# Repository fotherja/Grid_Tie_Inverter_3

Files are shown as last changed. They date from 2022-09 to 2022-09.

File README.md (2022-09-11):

# Grid_Tie_Inverter_3
Software and Hardware for GTI v3

Here the software and hardware files for the Grid Tie inverter project I'm working on. This is version 3. More to come soon.

I use STMCubeIDE for the software developer. I have used the CMSIS DSP library to do FFTs

I used Kicad to design the PCBs and the files are included here too

I'm working on a writeup - not quite finished yet.

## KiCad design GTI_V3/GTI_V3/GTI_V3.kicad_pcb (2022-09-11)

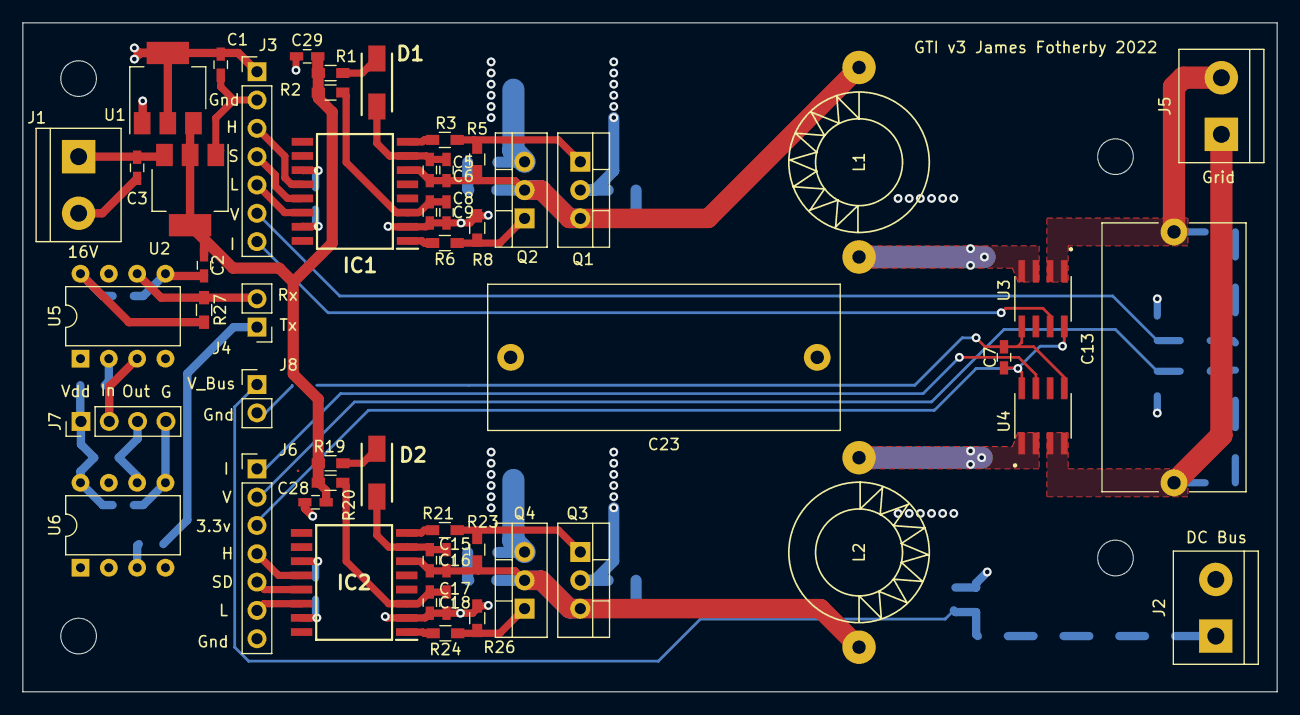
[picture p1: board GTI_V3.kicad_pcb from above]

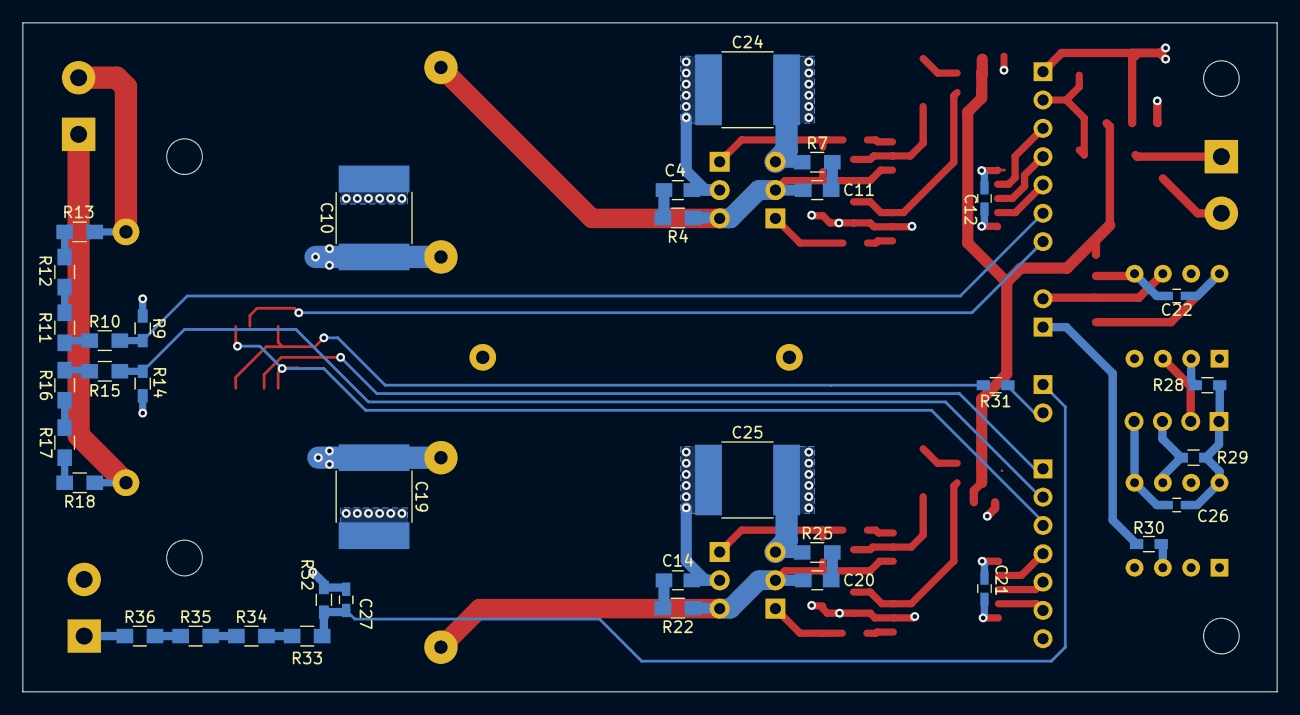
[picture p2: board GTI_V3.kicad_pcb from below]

Board: 4 copper layers, 112.5 x 60.0 mm, 89 parts (36 on the bottom side), 58 nets.

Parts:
C1, C2, C3: 10uF; C_0603_HandSoldering
C4, C11, C14, C20: 22pF; C_0805_HandSoldering
C5, C7, C8, C12, C15, C17, C21, C22, C26, C28, C29: 100nF; C_0603_HandSoldering
C6, C9, C16, C18: 2.2uF; C_0603_HandSoldering
C10, C19: C; C_2225_HandSoldering
C13: 2uF; C_Rect_L24.0mm_W12.8mm_P22.50mm_MKT
C23: 10uF; C_Rect_L31.5mm_W13.0mm_P27.50mm_MKS4
C24, C25: 0.47uF; C_2225_HandSoldering
C27: 10nF; C_0603_HandSoldering
D1, D2: ES1J; DIOM5227X250N
IC1, IC2: DGD2110S16-13; SOIC127P1032X264-16N
J1, J2, J5: Screw_Terminal_01x02; TerminalBlock_bornier-2_P5.08mm
J3, J6: Conn_01x07_Male; Socket_Strip_Straight_1x07_Pitch2.54mm
J4, J8: Conn_01x02_Male; Socket_Strip_Straight_1x02_Pitch2.54mm
J7: Conn_01x04_Male; Socket_Strip_Straight_1x04_Pitch2.54mm
L1, L2: L; Choke_Toroid_horizontal_Diameter12-5mm_Amidon-T44
Q1, Q2, Q3, Q4: STF35N60DM2; TO-220-3_Vertical
R1, R2, R19, R20: 2.2R; R_0603_HandSoldering
R3, R6, R21, R24: 4.7R; R_0603_HandSoldering
R4, R7, R22, R25: 15R; R_0805_HandSoldering
R5, R8, R23, R26: 10K; R_0603_HandSoldering
R9, R14, R32: 2.2K; R_0603_HandSoldering
R10, R11, R12, R13, R15, R16, R17, R18, R33, R34, R35, R36: 100K; R_0805_HandSoldering
R27, R29: 470R; R_0603_HandSoldering
R28, R30: 330R; R_0603_HandSoldering
R31: 0R; R_0603_HandSoldering
U1: NCP1117-3.3_SOT223; SOT-223-3_TabPin2
U2: NCP1117-12_SOT223; SOT-223-3_TabPin2
U3, U4: ACS722LLCTR-05AB-T; SOIC127P600X175-8N
U5, U6: 6N137; DIP-8_W7.62mm

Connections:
+3V3: C1.1, C7.1, C12.1, C21.1, C22.1, IC1.11 (VDD), IC2.11 (VDD), J3.1, J6.3, R27.2, U1.2 (VO), U3.8 (VCC), U4.8 (VCC), U5.8 (VCC), U6.2 (A)
+12V: C2.1, C28.1, C29.1, R1.2, R2.2, R19.2, R20.2, U1.3 (VI), U2.2 (VO)
/Ext_Gnd: C26.2, J7.4, U6.5 (GND)
/Ext_Rx: J7.3, R29.1, U6.6 (VO)
/Ext_Tx: J7.2, U5.3 (C)
/Ext_Vdd: C26.1, J7.1, R28.2, R29.2, U6.8 (VCC)
/I_Sense_A: J3.7, U3.7 (VIOUT)
/I_Sense_B: J6.1, U4.7 (VIOUT)
/Rx: J4.2, R27.1, U5.6 (VO)
/Tx: J4.1, R30.1
/VBUS_Sense: C27.1, J8.1, R32.2, R33.2
/V_Sense_A: J3.6, R9.2, R10.2
/V_Sense_B: J6.2, R14.2, R15.2
GND: C1.2, C2.2, C3.2, C8.2, C9.2, C10.2, C12.2, C17.2, C18.2, C19.2, C21.2, C22.2, C23.2, C24.2, C25.2, C27.2, C28.2, C29.2, IC1.2 (COM), IC1.15 (VSS), IC2.2 (COM), IC2.15 (VSS), J1.2, J2.2, J3.2, J6.7, J8.2, Q2.3 (S), Q4.3 (S), R7.1, R8.2, R9.1, R14.1, R25.1, R26.2, R31.1, R32.1, U1.1 (GND), U2.1 (GND), U5.5 (GND)
GNDA: C7.2, R31.2, U3.5 (GND), U4.5 (GND)
unnamed: C4.2, R4.2
unnamed: C5.1, C6.1, D1.1, IC1.7 (VB)
unnamed: C8.1, C9.1, IC1.3 (VCC), R2.1
unnamed: C10.1, L1.2, U3.3 (IP-), U3.4 (IP-)
unnamed: C5.2, C6.2, C11.1, IC1.6 (VS), L1.1, Q1.3 (S), Q2.2 (D), R4.1, R5.2
unnamed: C11.2, R7.2
unnamed: C13.1, J5.2, R13.1, U3.1 (IP+), U3.2 (IP+)
unnamed: C13.2, J5.1, R18.1, U4.3 (IP-), U4.4 (IP-)
unnamed: C14.2, R22.2
unnamed: C15.1, C16.1, D2.1, IC2.7 (VB)
unnamed: C15.2, C16.2, C20.1, IC2.6 (VS), L2.1, Q3.3 (S), Q4.2 (D), R22.1, R23.2
unnamed: C17.1, C18.1, IC2.3 (VCC), R20.1
unnamed: C19.1, L2.2, U4.1 (IP+), U4.2 (IP+)
unnamed: C20.2, R25.2
unnamed: D1.2, R1.1
unnamed: D2.2, R19.1
unnamed: IC1.1 (LO), R6.2
unnamed: IC1.8 (HO), R3.2
unnamed: IC1.12 (HIN), J3.3
unnamed: IC1.13 (SD), J3.4
unnamed: IC1.14 (LIN), J3.5
unnamed: IC2.1 (LO), R24.2
unnamed: IC2.8 (HO), R21.2
unnamed: IC2.12 (HIN), J6.4
unnamed: IC2.13 (SD), J6.5
unnamed: IC2.14 (LIN), J6.6
unnamed: Q1.1 (G), R3.1, R5.1
unnamed: Q2.1 (G), R6.1, R8.1
unnamed: Q3.1 (G), R21.1, R23.1
unnamed: Q4.1 (G), R24.1, R26.1
unnamed: R10.1, R11.2
unnamed: R11.1, R12.2
unnamed: R12.1, R13.2
unnamed: R15.1, R16.2
unnamed: R16.1, R17.2
unnamed: R17.1, R18.2
unnamed: R28.1, U5.2 (A)
unnamed: R30.2, U6.3 (C)
unnamed: R33.1, R34.2
unnamed: R34.1, R35.2
unnamed: R35.1, R36.2
VBUS: C4.1, C14.1, C23.1, C24.1, C25.1, J2.1, Q1.2 (D), Q3.2 (D), R36.1
VCC: C3.1, J1.1, U2.3 (VI)

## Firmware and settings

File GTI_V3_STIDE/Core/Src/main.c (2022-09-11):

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
/* Includes ------------------------------------------------------------------*/
#include "main.h"
#include "adc.h"
#include "dac.h"
#include "dma.h"
#include "tim.h"
#include "usart.h"
#include "gpio.h"

/* USER CODE BEGIN Includes */
//#define ARM_MATH_CM4 - WE HAVE DONE THIS UNDER OPTIONS FOR TARGET
#include "arm_math.h"
#include "math.h"
#include "support.h"
#include "PID.h"
#include "filter1.h"
#include "filter150.h"
#include "string.h"
#include "stdio.h"
/* USER CODE END Includes */

/* USER CODE BEGIN PD */
#define 		PLL_Kp 					4.0e-3f 								// PID parameters for our PLL tracking control
#define 		PLL_Ki 					2.0e-2f									// PoM: 4.0e-3f, 2.0e-2f
#define 		PLL_Kd 					0.0f
#define 		PLL_LIMIT 				500.0f
#define 		PLL_PERIOD 				7.8e-5f 								// 1 / (50 * 256) seconds
#define 		SINE_STEP_PERIOD 		13125 									// Ticks between incrementing our LO (Local Osc) index for 50Hz sine

//##############################################
#define			FC_Kp 					1.0e-3f									// Fundamental component PI parameter
#define 		FC_Ki 					8.0e-3f									//
#define 		FC_Limits 				1.5f

#define			HC_Kp 					1.0e-3f									// Harmonic component PI parameters
#define 		HC_Ki 					2.0e-3f
#define 		HC_Limits 				1.5f
//##############################################
#define 		SINE_STEPS           	256                         			// Number of steps to build our sine wave in
#define 		DUTY_LIMIT 				1000 									// Our duty width can vary from 0-1024 however we don't want 100% modulation to avoid MOSFET drive bootstrap voltage drop

#define 		I_OFFSET 				-4155 									// These are calibration constants for our hardware
#define 		V_OFFSET 				725
#define 		V_DIVIDER_K 			1.475e-1f
#define 		I_DIVIDER_K 			1.563e-3f
#define 		F_CONVERSION_K 			3.817e-3f

#define 		RMS_LOWER_LIMIT 		100.0f 									// These values are for the grid checks. We disconnect if our metrics are out of these ranges (SI Units)
#define 		RMS_UPPER_LIMIT 		130.0f
#define 		FREQ_DEVIATION_LIMIT 	1.0f
#define			V_BUS_MINIMUM			200.0f
#define 		V_BUS_MAXIMUM 			320.0f
#define 		I_OUTPUT_MAXIMUM 		4.0f

#define 		ENABLE_JOINING_GRID 	true
#define 		GRID_ACCEPTABLE 		1000
#define 		GRID_UNACCEPTABLE 		-1000
#define 		GRID_BAD_FAIL_RATE 		10 										// Some grid checks are allowed to fail for a certain amount of time (eg. Frequency) this parameter determines for how long
#define 		GRID_OK					0


#define 		CONSTRAIN(x,lower,upper) ((x)<(lower)?(lower):((x)>(upper)?(upper):(x)))
/* USER CODE END PD */


/* USER CODE BEGIN PV */
float Sin_LookupF[256] =
{
	0.00,6.28,12.56,18.83,25.09,31.34,37.56,43.77,49.94,56.09,62.20,68.28,74.31,80.30,86.24,92.13,
	97.97,103.74,109.45,115.10,120.68,126.18,131.61,136.96,142.23,147.41,152.50,157.50,162.40,167.21,171.92,176.52,
	181.02,185.41,189.68,193.85,197.89,201.82,205.62,209.30,212.86,216.28,219.58,222.74,225.77,228.67,231.42,234.04,
	236.51,238.85,241.04,243.08,244.98,246.73,248.33,249.78,251.08,252.23,253.23,254.07,254.77,255.31,255.69,255.92,

	256.00,255.92,255.69,255.31,254.77,254.07,253.23,252.23,251.08,249.78,248.33,246.73,244.98,243.08,241.04,238.85,
	236.51,234.04,231.42,228.67,225.77,222.74,219.58,216.28,212.86,209.30,205.62,201.82,197.89,193.85,189.68,185.41,
	181.02,176.52,171.92,167.21,162.40,157.50,152.50,147.41,142.23,136.96,131.61,126.18,120.68,115.10,109.45,103.74,
	97.97,92.13,86.24,80.30,74.31,68.28,62.20,56.09,49.94,43.77,37.56,31.34,25.09,18.83,12.56,6.28,

	0.00,-6.28,-12.56,-18.83,-25.09,-31.34,-37.56,-43.77,-49.94,-56.09,-62.20,-68.28,-74.31,-80.30,-86.24,-92.13,
	-97.97,-103.74,-109.45,-115.10,-120.68,-126.18,-131.61,-136.96,-142.23,-147.41,-152.50,-157.50,-162.40,-167.21,-171.92,-176.52,
	-181.02,-185.41,-189.68,-193.85,-197.89,-201.82,-205.62,-209.30,-212.86,-216.28,-219.58,-222.74,-225.77,-228.67,-231.42,-234.04,
	-236.51,-238.85,-241.04,-243.08,-244.98,-246.73,-248.33,-249.78,-251.08,-252.23,-253.23,-254.07,-254.77,-255.31,-255.69,-255.92,

	-256.00,-255.92,-255.69,-255.31,-254.77,-254.07,-253.23,-252.23,-251.08,-249.78,-248.33,-246.73,-244.98,-243.08,-241.04,-238.85,
	-236.51,-234.04,-231.42,-228.67,-225.77,-222.74,-219.58,-216.28,-212.86,-209.30,-205.62,-201.82,-197.89,-193.85,-189.68,-185.41,
	-181.02,-176.52,-171.92,-167.21,-162.40,-157.50,-152.50,-147.41,-142.23,-136.96,-131.61,-126.18,-120.68,-115.10,-109.45,-103.74,
	-97.97,-92.13,-86.24,-80.30,-74.31,-68.28,-62.20,-56.09,-49.94,-43.77,-37.56,-31.34,-25.09,-18.83,-12.56,-6.28
};

float Cos_LookupF[256] =
{
	256.00,255.92,255.69,255.31,254.77,254.07,253.23,252.23,251.08,249.78,248.33,246.73,244.98,243.08,241.04,238.85,
	236.51,234.04,231.42,228.67,225.77,222.74,219.58,216.28,212.86,209.30,205.62,201.82,197.89,193.85,189.68,185.41,
	181.02,176.52,171.92,167.21,162.40,157.50,152.50,147.41,142.23,136.96,131.61,126.18,120.68,115.10,109.45,103.74,
	97.97,92.13,86.24,80.30,74.31,68.28,62.20,56.09,49.94,43.77,37.56,31.34,25.09,18.83,12.56,6.28,

	0.00,-6.28,-12.56,-18.83,-25.09,-31.34,-37.56,-43.77,-49.94,-56.09,-62.20,-68.28,-74.31,-80.30,-86.24,-92.13,
	-97.97,-103.74,-109.45,-115.10,-120.68,-126.18,-131.61,-136.96,-142.23,-147.41,-152.50,-157.50,-162.40,-167.21,-171.92,-176.52,
	-181.02,-185.41,-189.68,-193.85,-197.89,-201.82,-205.62,-209.30,-212.86,-216.28,-219.58,-222.74,-225.77,-228.67,-231.42,-234.04,
	-236.51,-238.85,-241.04,-243.08,-244.98,-246.73,-248.33,-249.78,-251.08,-252.23,-253.23,-254.07,-254.77,-255.31,-255.69,-255.92,

	-256.00,-255.92,-255.69,-255.31,-254.77,-254.07,-253.23,-252.23,-251.08,-249.78,-248.33,-246.73,-244.98,-243.08,-241.04,-238.85,
	-236.51,-234.04,-231.42,-228.67,-225.77,-222.74,-219.58,-216.28,-212.86,-209.30,-205.62,-201.82,-197.89,-193.85,-189.68,-185.41,
	-181.02,-176.52,-171.92,-167.21,-162.40,-157.50,-152.50,-147.41,-142.23,-136.96,-131.61,-126.18,-120.68,-115.10,-109.45,-103.74,
	-97.97,-92.13,-86.24,-80.30,-74.31,-68.28,-62.20,-56.09,-49.94,-43.77,-37.56,-31.34,-25.09,-18.83,-12.56,-6.28,

	0.00,6.28,12.56,18.83,25.09,31.34,37.56,43.77,49.94,56.09,62.20,68.28,74.31,80.30,86.24,92.13,
	97.97,103.74,109.45,115.10,120.68,126.18,131.61,136.96,142.23,147.41,152.50,157.50,162.40,167.21,171.92,176.52,
	181.02,185.41,189.68,193.85,197.89,201.82,205.62,209.30,212.86,216.28,219.58,222.74,225.77,228.67,231.42,234.04,
	236.51,238.85,241.04,243.08,244.98,246.73,248.33,249.78,251.08,252.23,253.23,254.07,254.77,255.31,255.69,255.92
};

// structures
PIDControl 			PLL_PID; 													// These structures are used to store the respective PID variables
PIDControl 			Sin_50_PID, Cos_50_PID;
PIDControl 			Sin_150_PID, Cos_150_PID;
PIDControl 			Sin_250_PID, Cos_250_PID;
PIDControl 			Sin_350_PID, Cos_350_PID;

struct 				IIR_Filter_Struct V_Phase_Filter, I_Phase_Filter, V_Bus_Filter;

// DMA buffers and flags
volatile uint16_t 	V_Bus_Raw[1]; 												// ADC3 writes here via the DMA
volatile int32_t 	IV_Output_Raw[2]; 											// The DMA writes our synchronously sampled ADC1 & ADC2 samples here (I_Phase A&B and V_Phase A&B alternately)
volatile uint8_t 	HB_Enabled_Flag, UART_Ready_Flag;

// Voltage and Current values
volatile int16_t 	V_Phase_A, V_Phase_B, I_Phase_A, I_Phase_B;
volatile int16_t 	V_Phase_Unfiltered, I_Phase_Unfiltered, V_Bus_Unfiltered;
volatile float 		V_Phase, I_Phase, V_Bus, Mains_RMS_SI, Freq_Offset_SI; 		// These are our filtered SI unit values

volatile uint8_t 	_50_Index = 0;
volatile uint8_t 	_150_Index = 0;
volatile uint8_t 	_250_Index = 0;
volatile uint8_t 	_350_Index = 0;

volatile int16_t 	Grid_Good_Bad_Cnt = GRID_UNACCEPTABLE;
volatile uint8_t 	REQUEST_JOIN = false, Error_Code;
volatile float 		Joining_Amplitude;

char 				UART_Tx_Buffer[48];

volatile float32_t 	Period_Samples[64];
volatile uint8_t 	Period_Index, Calc_FFT_Flag, Phase_Shift;
volatile uint32_t 	Calc_FFT_Counter;

float32_t 			FFT_Input[64];
float32_t 			FFT_Complex_Output[64];



/* USER CODE END PV */

void SystemClock_Config(void);
/* USER CODE BEGIN PFP */
void HAL_ADC_ConvCpltCallback(ADC_HandleTypeDef* hadc);
void HAL_TIM_PeriodElapsedCallback(TIM_HandleTypeDef *htim);
void HAL_UART_TxCpltCallback(UART_HandleTypeDef *huart);
void Initialisations(void);
void HB_Disable(void);
void HB_Enable(void);
/* USER CODE END PFP */

/**
  * @brief  The application entry point.
  * @retval int
  */
int main(void)
{
  /* MCU Configuration--------------------------------------------------------*/

  /* Reset of all peripherals, Initialises the Flash interface and the Systick. */
  HAL_Init();

  /* Configure the system clock */
  SystemClock_Config();

  /* Initialize all configured peripherals */
  MX_GPIO_Init();
  MX_DMA_Init();
  MX_TIM1_Init();
  MX_TIM9_Init();
  MX_TIM10_Init();
  MX_TIM11_Init();
  MX_ADC1_Init();
  MX_ADC2_Init();
  MX_TIM3_Init();
  MX_ADC3_Init();
  MX_TIM2_Init();
  MX_USART2_UART_Init();
  MX_DAC_Init();
  MX_TIM12_Init();
  /* USER CODE BEGIN 2 */

  Initialisations();
  arm_rfft_fast_instance_f32 S;

  uint16_t i;

  /* USER CODE END 2 */

  /* Infinite loop */
  /* USER CODE BEGIN WHILE */
  while (1)
  {
	if(Calc_FFT_Flag == 1)
	{
		Calc_FFT_Flag = 0;

		// 1) Calculate the FFT of our output current waveform
		for(i = 0; i < 64; i++) {
			FFT_Input[i] = Period_Samples[i];
		}

		arm_rfft_fast_init_f32(&S, 64);
		arm_rfft_fast_f32(&S, FFT_Input, FFT_Complex_Output, 0);

		// 2) Extract the Sine/Cosine components from the 1,3,5,7th harmonics
		Sin_50_PID.input = FFT_Complex_Output[2];
		Cos_50_PID.input = FFT_Complex_Output[3];

		Sin_150_PID.input = FFT_Complex_Output[6];
		Cos_150_PID.input = FFT_Complex_Output[7];

		Sin_250_PID.input = FFT_Complex_Output[10];
		Cos_250_PID.input = FFT_Complex_Output[11];

		Sin_350_PID.input = FFT_Complex_Output[14];
		Cos_350_PID.input = FFT_Complex_Output[15];

		// 3) For each harmonic run a PI controller to compensate for the harmonics and eradicate them
		PIDCompute(&Sin_50_PID);
		PIDCompute(&Cos_50_PID);

		PIDCompute(&Sin_150_PID);
		PIDCompute(&Cos_150_PID);

		PIDCompute(&Sin_250_PID);
		PIDCompute(&Cos_250_PID);

		PIDCompute(&Sin_350_PID);
		PIDCompute(&Cos_350_PID);
	}

    /* USER CODE END WHILE */

    /* USER CODE BEGIN 3 */

  }
  /* USER CODE END 3 */
}

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
/* USER CODE BEGIN 4 */
void Initialisations() {
	// 1) Start the ADC engines - These continuously replenish circular buffers with fresh ADC readings
	HAL_ADC_Start(&hadc2);
	HAL_ADCEx_MultiModeStart_DMA(&hadc1, (uint32_t*)IV_Output_Raw, 2);
	HAL_ADC_Start_DMA(&hadc3, (uint32_t*)V_Bus_Raw, 1);

	// 2) Configure our PID parameters
	PIDInit(&PLL_PID, PLL_Kp, PLL_Ki, PLL_Kd, PLL_PERIOD, -PLL_LIMIT, PLL_LIMIT, AUTOMATIC, DIRECT, P_ON_M);

	PIDInit(&Sin_50_PID, FC_Kp, FC_Ki, 0.0f, 0.02f, -FC_Limits, FC_Limits, AUTOMATIC, DIRECT, P_ON_E);
	PIDInit(&Cos_50_PID, FC_Kp, FC_Ki, 0.0f, 0.02f, -FC_Limits, FC_Limits, AUTOMATIC, DIRECT, P_ON_E);

	PIDInit(&Sin_150_PID, HC_Kp, HC_Ki, 0.0f, 0.02f, -HC_Limits, HC_Limits, AUTOMATIC, DIRECT, P_ON_E);
	PIDInit(&Cos_150_PID, HC_Kp, HC_Ki, 0.0f, 0.02f, -HC_Limits, HC_Limits, AUTOMATIC, DIRECT, P_ON_E);

	PIDInit(&Sin_250_PID, HC_Kp, HC_Ki, 0.0f, 0.02f, -HC_Limits, HC_Limits, AUTOMATIC, DIRECT, P_ON_E);
	PIDInit(&Cos_250_PID, HC_Kp, HC_Ki, 0.0f, 0.02f, -HC_Limits, HC_Limits, AUTOMATIC, DIRECT, P_ON_E);

	PIDInit(&Sin_350_PID, HC_Kp, HC_Ki, 0.0f, 0.02f, -HC_Limits, HC_Limits, AUTOMATIC, DIRECT, P_ON_E);
	PIDInit(&Cos_350_PID, HC_Kp, HC_Ki, 0.0f, 0.02f, -HC_Limits, HC_Limits, AUTOMATIC, DIRECT, P_ON_E);

	// 3) Start our timers
	HAL_DAC_Start(&hdac, DAC_CHANNEL_1);
	HAL_TIM_Base_Start_IT(&htim2);
	HAL_TIM_Base_Start_IT(&htim3);
	HAL_TIM_Base_Start_IT(&htim9);
	HAL_TIM_Base_Start_IT(&htim10);
	HAL_TIM_Base_Start_IT(&htim11);
	HAL_TIM_Base_Start_IT(&htim12);

	// Initialise our filter coefficients
	V_Phase_Filter.alpha = 0.6f;
	I_Phase_Filter.alpha = 0.6f;
	V_Bus_Filter.alpha = 0.05f;

	sprintf(UART_Tx_Buffer, "%i\r", 0);
	HAL_UART_Transmit_DMA(&huart2, (uint8_t*)UART_Tx_Buffer, strlen(UART_Tx_Buffer));
	HAL_GPIO_WritePin(LED1_GPIO_Port, LED1_Pin, GPIO_PIN_SET);
}

void HB_Disable() {
	// Disable the H-Bridge
	HAL_TIM_PWM_Stop(&htim1, TIM_CHANNEL_1);
	HAL_TIMEx_PWMN_Stop(&htim1, TIM_CHANNEL_1);
	HAL_TIM_PWM_Stop(&htim1, TIM_CHANNEL_2);
	HAL_TIMEx_PWMN_Stop(&htim1, TIM_CHANNEL_2);

	HB_Enabled_Flag = false;
}

void HB_Enable() {
	// Start our PWM driver which uses Timer1 to power our H-bridge. Both channels start with Duty = 0
	HAL_TIM_PWM_Start(&htim1, TIM_CHANNEL_1);
	HAL_TIMEx_PWMN_Start(&htim1, TIM_CHANNEL_1);
	HAL_TIM_PWM_Start(&htim1, TIM_CHANNEL_2);
	HAL_TIMEx_PWMN_Start(&htim1, TIM_CHANNEL_2);

	HB_Enabled_Flag = true;
}

void HAL_UART_TxCpltCallback(UART_HandleTypeDef *huart) {
	UART_Ready_Flag = 1;
}

void HAL_ADC_ConvCpltCallback(ADC_HandleTypeDef* hadc) {
	// This callback extracts ADC data each time fresh values come in
	if(hadc == &hadc3)
	{
		V_Bus_Unfiltered = V_Bus_Raw[0];
		V_Bus = DSP_Filter(&V_Bus_Filter, (float)V_Bus_Unfiltered) * V_DIVIDER_K;
	}
	else
	{
		V_Phase_A = IV_Output_Raw[0] & 0xFFFF;
		V_Phase_B = IV_Output_Raw[0] >> 16;
		V_Phase_Unfiltered = V_Phase_A - V_Phase_B + V_OFFSET;

		I_Phase_A = IV_Output_Raw[1] & 0xFFFF;
		I_Phase_B = IV_Output_Raw[1] >> 16;
		I_Phase_Unfiltered = -(I_Phase_A + I_Phase_B + I_OFFSET);

		V_Phase = DSP_Filter(&V_Phase_Filter, (float)V_Phase_Unfiltered) * V_DIVIDER_K;
		I_Phase = DSP_Filter(&I_Phase_Filter, (float)I_Phase_Unfiltered) * I_DIVIDER_K;
	}
}

void HAL_TIM_PeriodElapsedCallback(TIM_HandleTypeDef *htim) {
	if (htim == &htim9)
	{
		// -----------------------------------------------------------------------------------------------------------------------------------
		// #################### Runs every 1ms to perform our grid/DC Bus checks etc for our anti-islanding ##################################
		// -----------------------------------------------------------------------------------------------------------------------------------

		// Calculate some grid metrics for some following checks
		Mains_RMS_SI = Integrate_Mains_RMS(V_Phase_Unfiltered) * V_DIVIDER_K; 			// Update our mains RMS measurement
		Freq_Offset_SI = PLL_PID.output * F_CONVERSION_K; 								// Get the frequency difference between the grid and a 50Hz reference

		// These are high priority checks:
		if(V_Bus > V_BUS_MAXIMUM)	{													// If our DC Bus voltage is too high cut-out immediately
			Grid_Good_Bad_Cnt = GRID_UNACCEPTABLE;
			Error_Code |= 0b00001;
		}

		if(I_Phase > I_OUTPUT_MAXIMUM || I_Phase < -I_OUTPUT_MAXIMUM)	{				// Likewise, if we detect excess current flowing, cut-out immediately
			Grid_Good_Bad_Cnt = GRID_UNACCEPTABLE;
			Error_Code |= 0b00010;
		}

		// These are lower priority checks and have to be out of range for an amount of time
		if(Mains_RMS_SI > RMS_UPPER_LIMIT || Mains_RMS_SI < RMS_LOWER_LIMIT)	{		// If mains RMS voltage whacky
			Grid_Good_Bad_Cnt -= GRID_BAD_FAIL_RATE;
			Error_Code |= 0b00100;
		}

		if(Freq_Offset_SI > FREQ_DEVIATION_LIMIT || Freq_Offset_SI < -FREQ_DEVIATION_LIMIT)	{
			Grid_Good_Bad_Cnt -= GRID_BAD_FAIL_RATE;									// If our mains frequency is out of tolerance
			Error_Code |= 0b01000;
		}

		if(V_Bus < V_BUS_MINIMUM)	{													// If our DC Bus voltage is too low
			Grid_Good_Bad_Cnt -= GRID_BAD_FAIL_RATE;
			Error_Code |= 0b10000;
		}

		// Act on the above checks
		if(Grid_Good_Bad_Cnt < GRID_OK && HB_Enabled_Flag) { 							// If our metrics have been whacky for too long stop output
			HB_Disable(); 																// This puts the H-bridge into a high impedance state
			Grid_Good_Bad_Cnt = GRID_UNACCEPTABLE;
		}

		if(HB_Enabled_Flag == false) { 													// With our output idle, if the grid has normalised, restart
			if(Grid_Good_Bad_Cnt == GRID_ACCEPTABLE && ENABLE_JOINING_GRID) {
				REQUEST_JOIN = true;
			}
		}

		// Constrain and decay any error counts
		Grid_Good_Bad_Cnt++;
		Grid_Good_Bad_Cnt = CONSTRAIN(Grid_Good_Bad_Cnt, GRID_UNACCEPTABLE, GRID_ACCEPTABLE);
	}

	if (htim == &htim10)
	{
		// -----------------------------------------------------------------------------------------------------------------------------------
		// ######### Runs every 100us to measure the instantaneous current output and adjust our PWM duty to reach setpoint current ###########
		// -----------------------------------------------------------------------------------------------------------------------------------
		static int16_t Duty_Cycle;

		// If we currently have disabled H-Bridges and are ready to join with the grid
		if(REQUEST_JOIN == true && _50_Index == 0) {
			Joining_Amplitude = (Mains_RMS_SI / V_Bus) * -6.7;

			REQUEST_JOIN = false;

			Cos_50_PID.setpoint = 0;													// We start we no requested output current

			Sin_50_PID.iTerm = 0;  Sin_50_PID.output = 0;
			Cos_50_PID.iTerm = 0;  Cos_50_PID.output = 0;
			Sin_150_PID.iTerm = 0; Sin_150_PID.output = 0;
			Cos_150_PID.iTerm = 0; Cos_150_PID.output = 0;
			Sin_250_PID.iTerm = 0; Sin_250_PID.output = 0;
			Cos_250_PID.iTerm = 0; Cos_250_PID.output = 0;
			Sin_350_PID.iTerm = 0; Sin_350_PID.output = 0;
			Cos_350_PID.iTerm = 0; Cos_350_PID.output = 0;

			HB_Enable();
		}

		float32_t _50_HC  = (Sin_50_PID.output * Sin_LookupF[_50_Index])   + (Cos_50_PID.output * Cos_LookupF[_50_Index]);
		float32_t _150_HC = (Sin_150_PID.output * Sin_LookupF[_150_Index]) + (Cos_150_PID.output * Cos_LookupF[_150_Index]);
		float32_t _250_HC = (Sin_250_PID.output * Sin_LookupF[_250_Index]) + (Cos_250_PID.output * Cos_LookupF[_250_Index]);
		float32_t _350_HC = (Sin_350_PID.output * Sin_LookupF[_350_Index]) + (Cos_350_PID.output * Cos_LookupF[_350_Index]);

		Duty_Cycle = (int16_t)(Sin_LookupF[_50_Index] * Joining_Amplitude) - (int16_t)_50_HC - (int16_t)_150_HC - (int16_t)_250_HC - (int16_t)_350_HC;

		// Constrain and output the new duty cycle
		Duty_Cycle = CONSTRAIN(Duty_Cycle, -DUTY_LIMIT, DUTY_LIMIT);

		if(Duty_Cycle >= 0) {
			htim1.Instance->CCR1 = Duty_Cycle;
			htim1.Instance->CCR2 = 0;
		}
		else {
			htim1.Instance->CCR1 = 0;
			htim1.Instance->CCR2 = -Duty_Cycle;
		}

		// Output to DAC for debugging
		//uint32_t DAC_Data = 2048 + (int32_t)(Duty_Cycle);
		uint32_t DAC_Data = 2048 + (int32_t)(Period_Samples[Period_Index]*500.0f);		// For debugging stuff

		HAL_DAC_SetValue(&hdac, DAC_CHANNEL_1, DAC_ALIGN_12B_R, DAC_Data);
	}

	if (htim == &htim11)
	{
		// -----------------------------------------------------------------------------------------------------------------------------------
		// ################### Keeps our local oscillator synchronised to the grid by implementing a PLL with PI controller ##################
		// -----------------------------------------------------------------------------------------------------------------------------------
		int32_t Signal_Multiple = (int32_t)Cos_LookupF[_50_Index] * V_Phase_Unfiltered; // Multiply the LO Cosine value with our current phase voltage sample
		PLL_PID.input = Integral(Signal_Multiple / (int32_t)Mains_RMS_SI);   			// Integrate this Multiple over the last 1 period normalised to RMS

		PIDCompute(&PLL_PID); 															// Plug result in a PI controller to maintain 0 phase shift
		TIM11->ARR = SINE_STEP_PERIOD - (int32_t)PLL_PID.output; 						// adjust LO frequency (step period) to synchronise to mains phase

		_50_Index += 1; _150_Index += 3; _250_Index += 5; _350_Index += 7; 				// Increment our LO indices, since they're 8bits wide they will roll-over if they exceed 255

		if(_50_Index % 4 == 0) { 														// Here we store a filtered average of current waveform over 1 period
			Period_Index = _50_Index/4;
			Period_Samples[Period_Index] = I_Phase; 									//Period_Samples[Period_Index] - (0.05f * (Period_Samples[Period_Index] - I_Phase));

			if(_50_Index == 0) {
				Calc_FFT_Flag = 1;
			}
		}
	}

	if (htim == &htim12)
	{
		// -----------------------------------------------------------------------------------------------------------------------------------
		// ################### Runs every 30ms  #############################################################################################
		// -----------------------------------------------------------------------------------------------------------------------------------
		if(UART_Ready_Flag) {
			UART_Ready_Flag = 0;
			//sprintf(UART_Tx_Buffer, "%f, %f\n", FFT_Complex_Output[2], FFT_Complex_Output[3]);
			sprintf(UART_Tx_Buffer, "%f, %f, %f, %i\n", Mains_RMS_SI, V_Bus, Joining_Amplitude, Error_Code);
			HAL_UART_Transmit_DMA(&huart2, (uint8_t*)UART_Tx_Buffer, strlen(UART_Tx_Buffer));

			Error_Code = 0;
		}

		// Ramp up our output current gradually
		Cos_50_PID.setpoint += 0.2f;
		if(Cos_50_PID.setpoint >= 70.0f)
			Cos_50_PID.setpoint = 70.0f;
	}
}
/* USER CODE END 4 */
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


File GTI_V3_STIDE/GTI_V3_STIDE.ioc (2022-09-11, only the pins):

Mcu.UserName=STM32F407VGTx
PA1.GPIO_Label=DC_Bus_V_Sense
PA1.Signal=ADCx_IN1
PA2.Signal=USART2_TX
PA3.Signal=USART2_RX
PA4.Signal=COMP_DAC1_group
PA7.GPIO_Label=Ph_AN_PWM
PA7.Signal=TIM1_CH1N
PB0.GPIO_Label=Ph_BN_PWM
PB0.Signal=TIM1_CH2N
PC0.GPIO_Label=Phase_B_V_Sense
PC0.Signal=ADCx_IN10
PC1.GPIO_Label=Phase_B_I_Sense
PC1.Signal=ADCx_IN11
PC2.GPIO_Label=Phase_A_V_Sense
PC2.Signal=ADCx_IN12
PC3.GPIO_Label=Phase_A_I_Sense
PC3.Signal=ADCx_IN13
PD13.GPIO_Label=LED1
PD13.Signal=GPIO_Output
PE11.GPIO_Label=Ph_B_PWM
PE11.Signal=S_TIM1_CH2
PE9.GPIO_Label=Ph_A_PWM
PE9.Signal=S_TIM1_CH1
PH0-OSC_IN.Signal=RCC_OSC_IN
PH1-OSC_OUT.Signal=RCC_OSC_OUT

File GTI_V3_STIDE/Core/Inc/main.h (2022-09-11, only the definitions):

#define Phase_B_V_Sense_Pin GPIO_PIN_0
#define Phase_B_V_Sense_GPIO_Port GPIOC
#define Phase_B_I_Sense_Pin GPIO_PIN_1
#define Phase_B_I_Sense_GPIO_Port GPIOC
#define Phase_A_V_Sense_Pin GPIO_PIN_2
#define Phase_A_V_Sense_GPIO_Port GPIOC
#define Phase_A_I_Sense_Pin GPIO_PIN_3
#define Phase_A_I_Sense_GPIO_Port GPIOC
#define DC_Bus_V_Sense_Pin GPIO_PIN_1
#define DC_Bus_V_Sense_GPIO_Port GPIOA
#define Ph_AN_PWM_Pin GPIO_PIN_7
#define Ph_AN_PWM_GPIO_Port GPIOA
#define Ph_BN_PWM_Pin GPIO_PIN_0
#define Ph_BN_PWM_GPIO_Port GPIOB
#define Ph_A_PWM_Pin GPIO_PIN_9
#define Ph_A_PWM_GPIO_Port GPIOE
#define Ph_B_PWM_Pin GPIO_PIN_11
#define Ph_B_PWM_GPIO_Port GPIOE
#define LED1_Pin GPIO_PIN_13
#define LED1_GPIO_Port GPIOD

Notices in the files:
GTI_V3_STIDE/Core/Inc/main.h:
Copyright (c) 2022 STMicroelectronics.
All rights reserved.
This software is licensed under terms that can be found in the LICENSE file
